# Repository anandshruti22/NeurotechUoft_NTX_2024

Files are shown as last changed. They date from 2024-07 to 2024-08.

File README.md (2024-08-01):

# NeurotechUoft_NTX_2024
The University of Toronto's Neurotechnology design team's submission to NTX competition 2024

## Contributors:
##### Software Subsystem: 
* Subsystem Lead: Shruti Anand (Undergrad Biomedical Engineering, Year 3) 
* Subsystem Members: Brandon Wong (Undergrad Computer Science, Year 2), Naoroj Farhan (Undergrad Computer Science, Year 1), Yunran Yang (Undergrad Computer Engineering, Year 2)
##### Hardware Subsystem:
* Subsystem Lead: Shuntaro Wakamatsu (Undergrad Computer Engineering, Year 3)
* Subsystem Members:
  Nafew Islam (Undergrad Mechanical Engineering, Year 2),
  Robert Youssef (Undergrad Mechanical Engineering, Year 2),
  Luna Sun (Undergrad Electrical Engineering, Year 2)

## Description of Project: 

About 15% of the world's population lives with some form of disability, of whom 2-4% experience significant difficulties in functioning. Among this statistic are individuals with weakened grip strength or hand amputees. Weakened grip strength or inability to perform grasping motions strongly limit the ability to perform daily household tasks. 

Our aim is to create a prototype of a mind controlled prosthetic hand that can conduct hand grasping motions based on the user’s thoughts. The objectives of our design are to: 
1) Create a prosthetic hand that can conduct the following two motions:
* Opening hand 
* Closing hand 

2) Identify the above two hand motions from EEG signals 

3) Retrieve relevant EEG signals from OpenBCI headset

## Pipeline:

The flow of data in our EEG controlled prosthetic hand works as follows:
1) Setup and Connection: Connect the OpenBCI headset to the OpenBCI Cyton board.
2) Data Transmission: Communicate with  Raspberry Pi through OpenBCI dongle. 
3) Data Streaming: Implement BrainFlow to stream EEG data live.
4) Data Processing : Run signal processing algorithms to denoise the EEG signals.
5) Machine Learning Model Execution : Execute the machine learning model to classify EEG signals.
6) Communication with Arduino: Send the result of the ML model to an Arduino via serial communication
7) Hand Motion: Arduino instructs the motors on the prosthetic hand to conduct the specified hand motion

## Navigation

Navigate through our repository and find the following information: 

* Software Subsystem: Our code to preprocess training data, train our ML model, and test our ML model using data we collected.
* Hardware Subsystem: Our CAD Files containing our prosthetic hand design, hand assembly instructions, Arduino code to control the hand, and a PCB design to be implemented in future iterations.
* Presentation: Our Presentation recording and the associated slides.

## Equipment and Software Installation: 

### Hardware Equipment required: 
* Raspberry Pi 4
* Arduino
* Jumper wires
* 2 Arduino Power Supply Modules
*  5 SG90 servo motors
*  PLA for 3d Printing
*  Rubber bands
*  USB-A to MicroUSB cable
*  2 AC to DC power coverters
  
### Software libraries to be installed: 
Read requirements.txt file for python libraries needed to run the code in the software subsystem folder.

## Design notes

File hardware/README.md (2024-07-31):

# EEG-Controlled Prosthetic Arm

## Overview
The EEG-Controlled Prosthetic Arm project aims to create a functional prosthetic arm that responds to brain signals. By integrating an EEG (electroencephalogram) headset, a 3D printed hand, a microcontroller, and servo motors, this project enables users to control the arm using their brain activity.

## CAD Files
The project includes the following CAD files:

- **Fingers**: There are 10 files for the fingers, each corresponding to a specific joint of a finger. These files are exported in both `.3mf` and `.f3d` formats (located in `hardware/CADfiles/3mf` and `hardware/CADfiles/f3d`, respectively).
- **Palm**: The palm design consists of two files: one cover and one main body (located in `hardware/CADfiles/palm`).
- **Shaft**: The shaft file (located in `hardware/CADfiles/shaft`) connects the finger joints. It has a diameter of approximately 2.8mm The shafts should be glued to the outer wall of the junction part so that it allows the inner part to move freely. The junction parts are designed not to bend more than 90 degrees or bend backwards.

## 3D Prints Assembly
To assemble the 3D prints:
- Place the motors inside the palm and glue them for maximum steadiness
- Put the string through the holes of each finger component
- Connect each finger joint using the 3D printed shafts.
- hook the rubber bands
- Push the cover of the palm into the main body (no need for gluing).

## Motors
The prosthetic arm features 5 SG90 servo motors placed inside the palm. Continuous motors were chosen because of their ability to keep winding. The choice of continuous motors allows for more rotations with a smaller radius, eliminating the need for bulky servo motor horns or attachments. This design optimization enables us to fit the motors comfortably inside the hand. Here's how they are set up:

- **Motor Placement**: The servo motors are strategically positioned within the palm to drive finger movements. There are small poles inside the palm that guides the string to its corresponding motor.
- **Control**: An Arduino microcontroller (tested with Arduino Due) runs the `control.ino` code (located in `hardware/ArduinoCode/control.ino`) to manage motor rotation.
- **String Mechanism**: For each finger, a strong (able to withstand at least 6kg of load) string (with a diameter of no more than 2.0 mm) is threaded through holes in the finger components. At the fingertip, the strings are securely tied to prevent them from slipping out. The other end of the strings is firmly attached to the servo motor shaft using modified servo motor horns and super glue. The horns create a groove where the strings wind and unwind.
- **Motor Control Wires**: (the group of wires in the red circle in the image below) The wires from the motors exit through five square windows at the wrist cross-section. The power pins (orange) receive 5V voltage and draw a current of 360mA. Since Arduino Due has only one 5V pin, two Arduino Power Supply Modules provide additional 4 5V power pins (2 power pins for each supply module). The ground pins (black) of the motors are connected to the same voltage. Control pins (yellow) are connected to the digital pins of the Arduino Due as follows:
  - Thumb:   Pin 2
  - Index:   Pin 9
  - Middle:  Pin 10
  - Ring:    Pin 11
  - Pinky:   Pin 12
  - 
- **Feedback Wires**: (the group of wires in the blue circle in the image above) On top of each finger, wires form a closed circuit. One end connects to a 3.3V power source, while the other end attaches to the analog pins of the Arduino Due:
  - Index:   A0
  - Middle:  A1
  - Ring:    A2
  - Pinky:   A3
  - A short jumper wire with woven edges ensures good contact. When the fingers are fully extended, the woven edges touch, creating a 3.3V signal. Arduino detects this and stops motor rotation.
  - On both sides of each finger, wires are attached to form a closed circuit. Electrons flow toward the fingertip on one side and return from the tip on the other side. (see the image below)
  - At the fingertip, a 1k ohm resistor is attached. This prevents the formation of a short circuit and ensures stable operation.
  - This closed circuit is independently implemented for each finger allowing the Arduino to control them separately.
  - 

- **Rubber Bands**: Plastic hair ties hooked onto small protrusions on each finger joint assist in retracting the fingers when the motor unwinds. Adjust their length to maintain tension.

## Arduino
Upload the "control.ino" file to the Arduino Due using the Arduino IDE software. Connect Arduino to the Raspberry Pi using a USB-A to MicroUSB cable for communication.

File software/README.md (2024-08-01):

# Files

## Raspberry Pi
```
├── real_time_processing.py: code loaded onto raspberry pi that interpets EEG signals and sends ML model output to Arduino via serial communication
```

## Data 

```
├── data_1_4_Hz
│   ├── processed training data files (bandpass filter of 1-4Hz + epoch)
├── data_13_17_Hz
│   ├── processed training data files (bandpass filter of 13-17Hz + baseline correction + epoch)
├── test_data
│   ├── processed test data files (bandpass filter of 1-4Hz + epoch)
│   ├── processed training data files (bandpass filter of 13-17Hz + baseline correction + epoch)
│   ├── data_collection_method.md: description on how test data was collected
│   ├── testing_model.md: python notebook where test data was used to see performance of model
```

## Preprocessing Code
```
├── Preprocessing
│   ├── preprocessing.ipynb: preprocessing code showing time frequency analysis and epoching
│   ├── citations.md: Details regarding citations justifying our use of C2, C4, Cz channels
│   ├── raw_data.md: Link to the raw data that is used for model training
```

## ML Model
```
├── ML Model
│   ├── model_training.ipynb: model training code
│   ├── model_with_delta.keras: model to be loaded
│   ├── model_description.md: Details regarding model architecture and citations
```

# How to run
To integrate with the prosthetic hand simple load the real_time_processing.py file along with the model_with_delta.keras file onto the Raspberry Pi. Then, run the real_time_preocessing.py code on the Raspberry Pi.

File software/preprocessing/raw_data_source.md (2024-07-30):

# Link to raw data used for preprocessing and training data
EEG Motor Movement/Imagery Dataset: https://www.physionet.org/content/eegmmidb/1.0.0/

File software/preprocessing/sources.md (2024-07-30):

# Citations

Yahya, Norashikin, et al. “Classification of Motor Functions from Electroencephalogram (EEG) Signals Based on an Integrated Method Comprised of Common Spatial Pattern and Wavelet Transform Framework.” Sensors (Basel, Switzerland), U.S. National Library of Medicine, 8 Nov. 2019, www.ncbi.nlm.nih.gov/pmc/articles/PMC6891287/.

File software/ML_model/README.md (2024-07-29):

# EEG Classification with Temporal Convolutional Neural Networks (TCNN)

## Overview
For our project, we used a temporal Convolution Neural Network that uses 1d convolutions over the EEG data and then makes a class prediction with a final sigmoid layer.
We did this for a few reasons:
- we faced significant issues with vanishing and exploding gradients when attempting to train an RNN/LSTM-based model for EEG classification tasks.
- RNNs/LSTMs take significantly longer to train well than CNNs

To address these challenges, we explored the use of Temporal Convolutional Neural Networks (TCNNs), which have shown success in similar tasks such as motion imagery classification (Lun et al., 2020). This document outlines the architecture, training strategy, and performance of our TCNN model.

## Model Architecture
We designed our TCNN model with the following key components and considerations:

- **Significant Dropout (80%)**: Applied to reduce overfitting to the training dataset.
- **He Initialization**: Used in convolutional layers to mitigate vanishing/exploding gradients (He et al., 2015).
- **Large Number of Filters**: Employed in the 1D convolutional layers (32, 64) to capture a richer set of features from the EEG input data.

Our model is inspired by the architecture used by Lun et al. but we simplified the architecture slightly to reduce overfitting in our specific task. Below is the model architecture the aforementioned paper used.
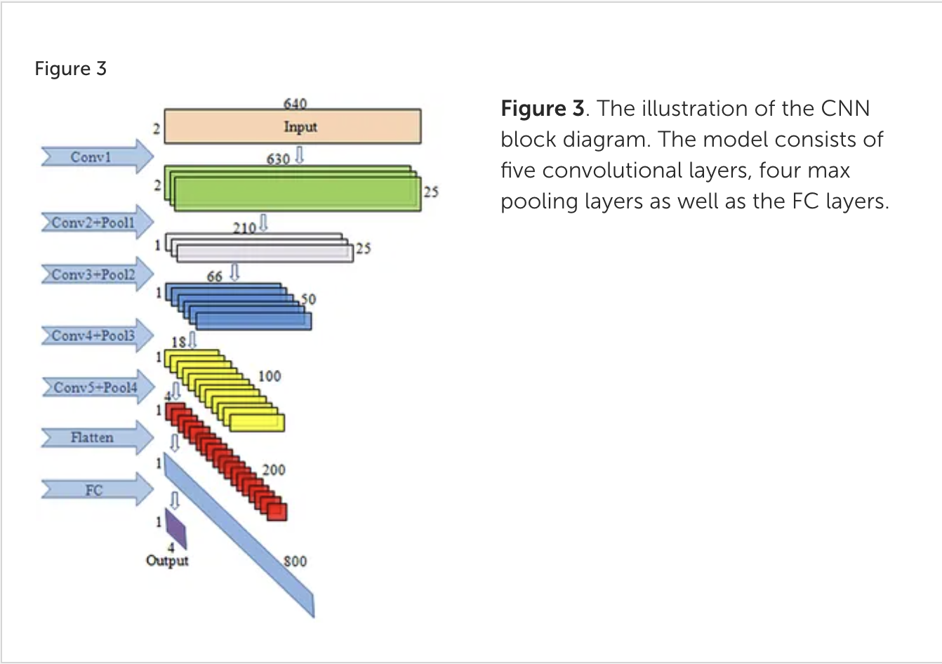
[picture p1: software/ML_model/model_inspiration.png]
Model Architecture

### Model Code
```python
from tensorflow.keras import layers, models, initializers

def create_model():
    dropout_rate = 0.2
    input_layer = layers.Input(shape=(401, 6))

    x = layers.Conv1D(filters=32, kernel_size=3, strides=2, activation='relu', kernel_initializer=initializers.HeNormal(), padding="same")(input_layer)
    x = layers.BatchNormalization()(x)
    x = layers.MaxPooling1D(pool_size=2, strides=2)(x)

    x = layers.Conv1D(filters=64, kernel_size=3, strides=2, activation='relu', kernel_initializer=initializers.HeNormal(), padding="same")(x)
    x = layers.BatchNormalization()(x)
    x = layers.MaxPooling1D(pool_size=2, strides=2)(x)

    x = layers.Conv1D(filters=128, kernel_size=3, strides=2, activation='relu', kernel_initializer=initializers.HeNormal(), padding="same")(x)
    x = layers.BatchNormalization()(x)
    x = layers.MaxPooling1D(pool_size=2, strides=2)(x)

    x = layers.Flatten()(x)

    x = layers.Dense(1024, activation="relu", kernel_initializer=initializers.HeNormal())(x)
    x = layers.Dropout(dropout_rate)(x)

    x = layers.Dense(256, activation="relu", kernel_initializer=initializers.HeNormal())(x)
    x = layers.Dropout(dropout_rate)(x)

    output_layer = layers.Dense(1, kernel_initializer=initializers.HeNormal(), activation="sigmoid")(x)

    return models.Model(inputs=input_layer, outputs=output_layer)
```

## Training Strategy
We employed several strategies to improve the performance and stability of our model:

- **Hyperparameter Tuning**: Adjusted learning rates, learning rate schedules, and the number of epochs.
- **Learning Rate Schedule**: Implemented to ensure stable convergence. If the model's loss did not improve after 3 epochs, the learning rate was reduced by 10%.
- **Repeated Training**: Conducted short training sessions (50 epochs) with hyperparameter adjustments to iteratively improve model performance.

### Key Considerations
1. **Dropout**: To counteract overfitting, significant dropout was applied. Initial experiments showed that training accuracy was often 15-20% higher than validation accuracy.
2. **Model Complexity**: While reducing the number of units in dense layers decreased both training and validation accuracy, maintaining a higher complexity was necessary to avoid high bias and variance.
3. **Vanishing/Exploding Gradients**: Although TCNNs are less prone to these issues compared to RNN/LSTM networks, He initialization was crucial to mitigate potential problems.

## Performance Metrics
Our evaluation metrics included binary accuracy, area under the curve (AUC), precision, and recall. We compared our model's performance against existing literature and other models trained on the same dataset.

### Results
- **Training Data**:
  - Classification Accuracy: 80%
  - Precision: 80%
  - Recall: 88%
  
- **Test Data**:
  - Classification Accuracy: 74%
  - Precision: 80%
  - Recall: 79%

These results are competitive with other machine learning models used for motor imagery tasks.

### Own Data Collection
We collected additional data in a manner similar to the dataset's original collection process. Our model achieved around 80% accuracy in predicting hand motions on this new data as well.

## Citation
He, K., Zhang, X., Ren, S., & Sun, J. (2015, February 6). Delving deep into rectifiers: Surpassing human-level performance on ImageNet Classification. arXiv.org. https://arxiv.org/abs/1502.01852 <br>
Lun, X., Yu, Z., Chen, T., Wang, F., & Hou, Y. (2020a, July 31). A simplified CNN classification method for Mi-EEG via the electrode pairs signals. Frontiers. https://www.frontiersin.org/articles/10.3389/fnhum.2020.00338/full#B10 

## Summary
Our approach focused on hyperparameter tuning and short epoch training sessions while adjusting learning rates and schedules to achieve stable convergence. The use of TCNNs with He initialization and significant dropout proved effective in addressing the vanishing/exploding gradient issues, resulting in competitive performance in EEG classification tasks.

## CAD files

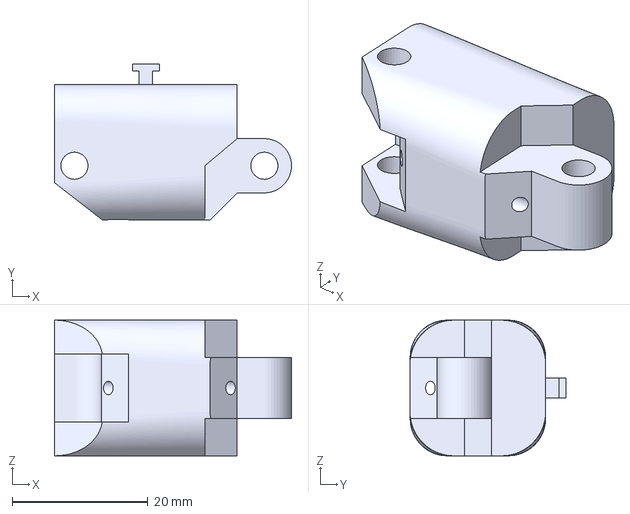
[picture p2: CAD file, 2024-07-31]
hardware/CADfiles/3mf/Middle Finger Second Joint Edited v7.3mf
34.9 x 23.0 x 20.0 mm

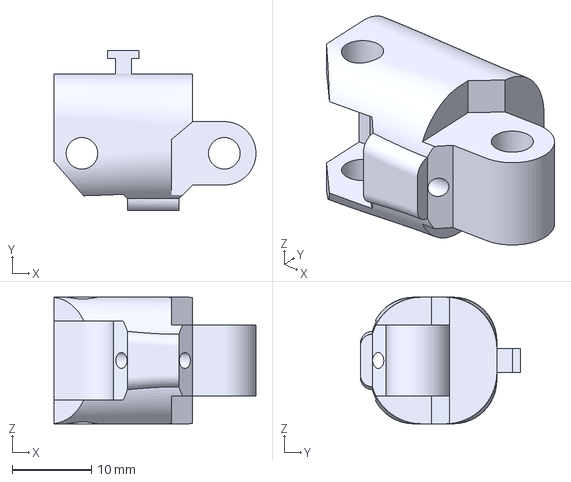
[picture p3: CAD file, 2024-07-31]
hardware/CADfiles/3mf/Pinky Finger Second Joint Edited v10.3mf
25.5 x 20.2 x 16.0 mm

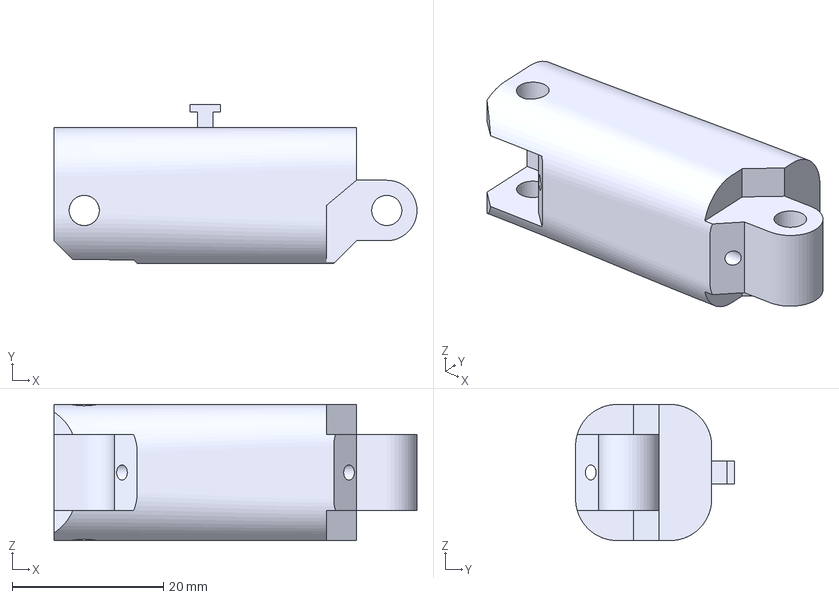
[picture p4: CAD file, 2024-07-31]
hardware/CADfiles/3mf/Ring Finger Base Joint v5.3mf
48.0 x 21.0 x 18.0 mm

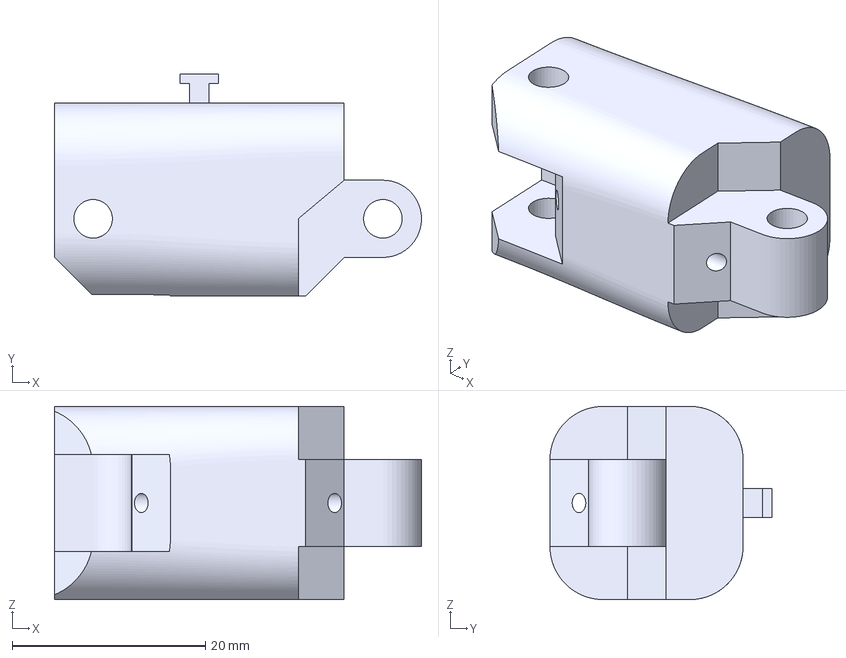
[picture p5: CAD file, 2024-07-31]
hardware/CADfiles/3mf/Thumb Base Joint v5.3mf
38.0 x 23.0 x 20.0 mm

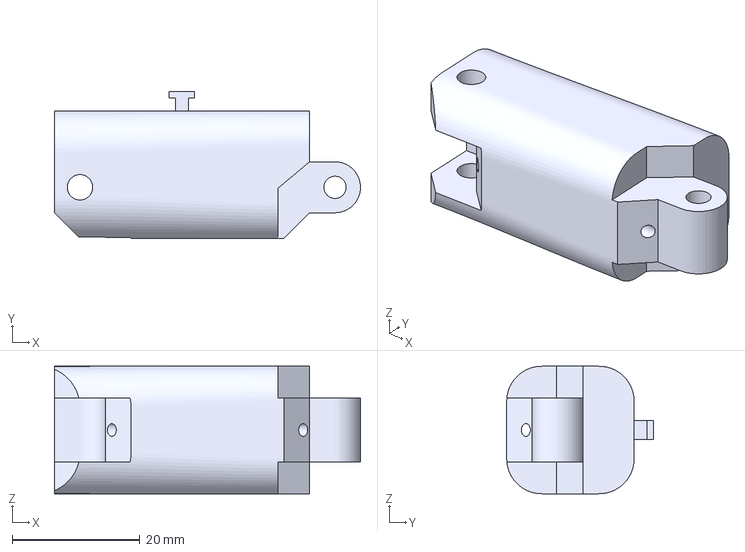
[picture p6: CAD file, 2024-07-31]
hardware/CADfiles/3mf/Index Finger Base Joint v5.3mf
48.0 x 23.0 x 20.0 mm

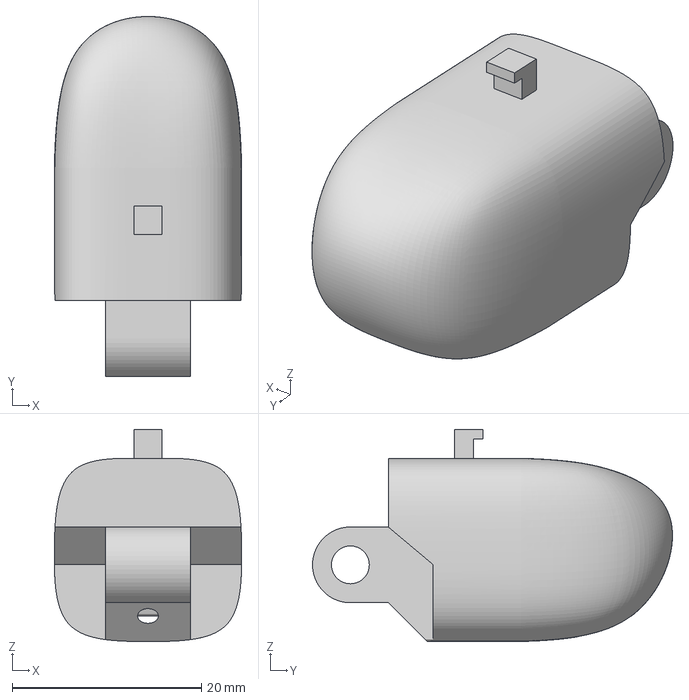
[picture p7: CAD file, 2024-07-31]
hardware/CADfiles/3mf/Tip Joint v6.3mf
19.8 x 38.0 x 22.4 mm

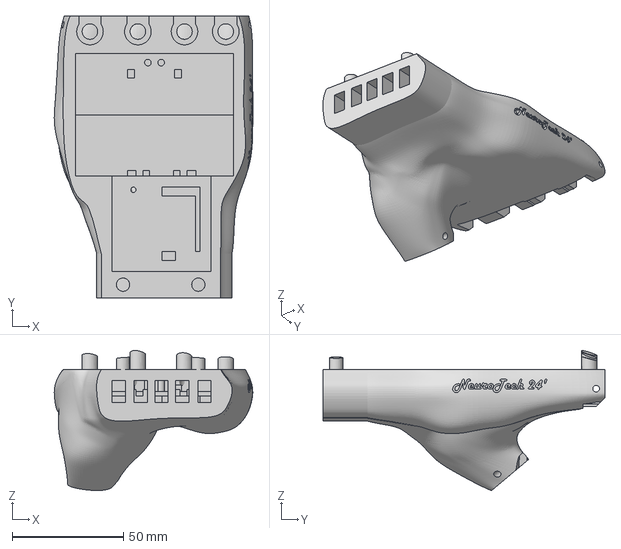
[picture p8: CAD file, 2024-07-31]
hardware/CADfiles/3mf/Palm7 v10.3mf
89.4 x 127.0 x 63.1 mm

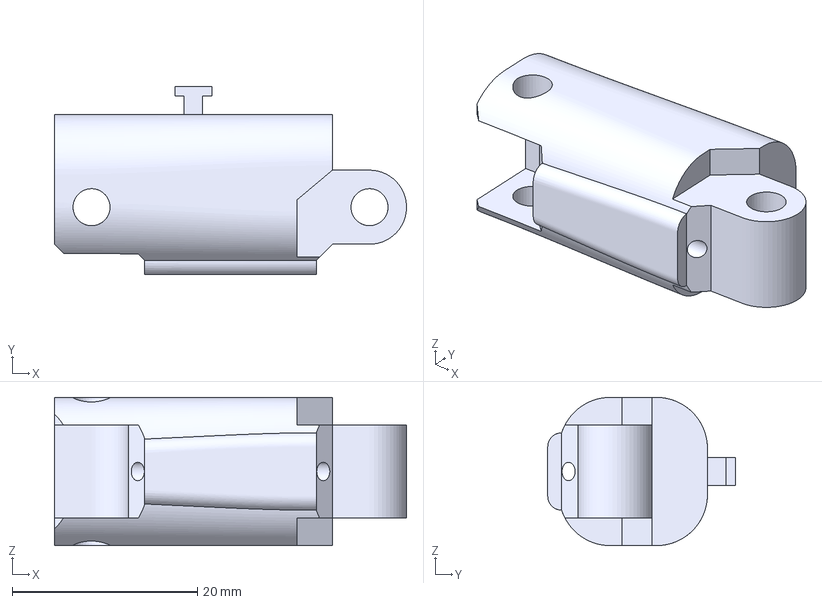
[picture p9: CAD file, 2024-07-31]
hardware/CADfiles/3mf/Pinky Finger Base Joint v6.3mf
38.0 x 20.2 x 16.0 mm

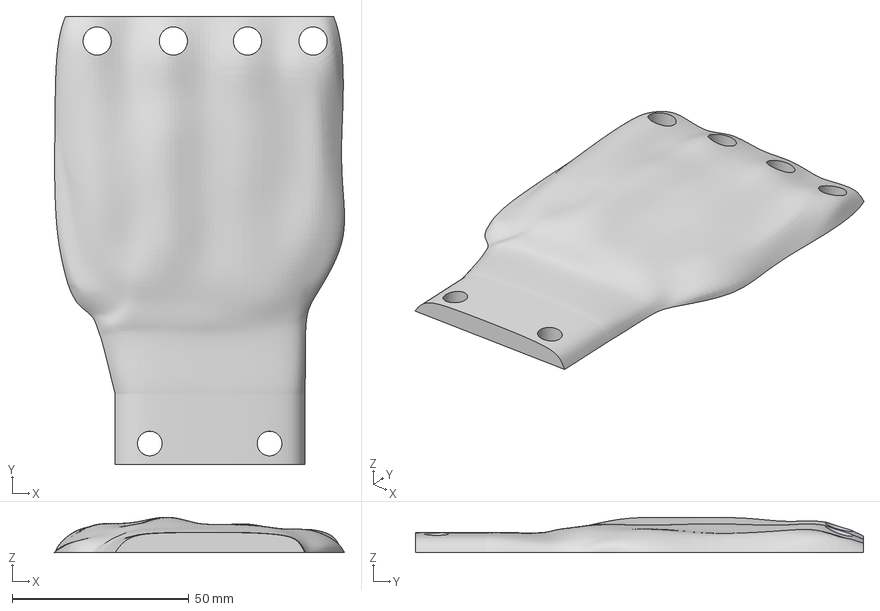
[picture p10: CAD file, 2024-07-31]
hardware/CADfiles/3mf/Palm6 v10.3mf
82.1 x 127.0 x 9.99 mm

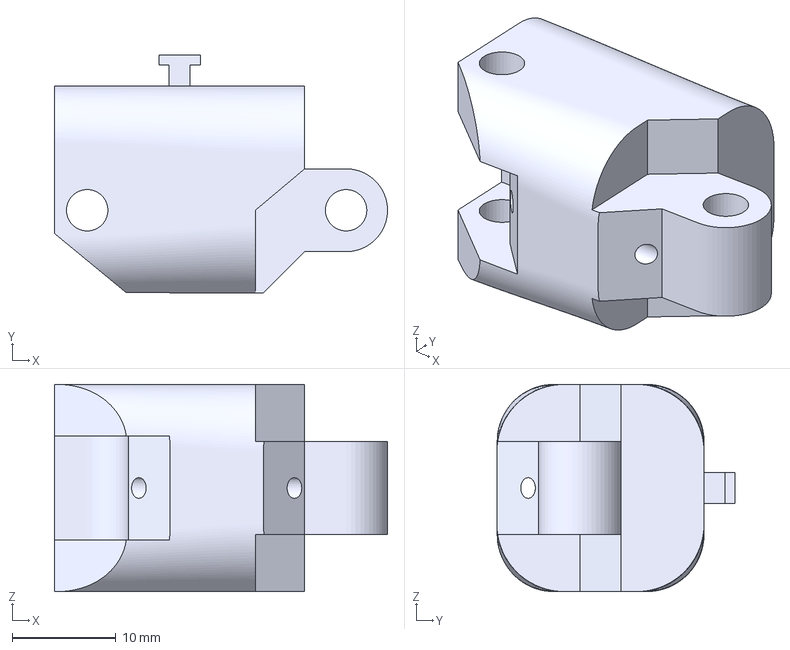
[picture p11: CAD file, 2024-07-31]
hardware/CADfiles/3mf/Index Finger Second Joint Edited v9.3mf
32.2 x 23.0 x 20.0 mm

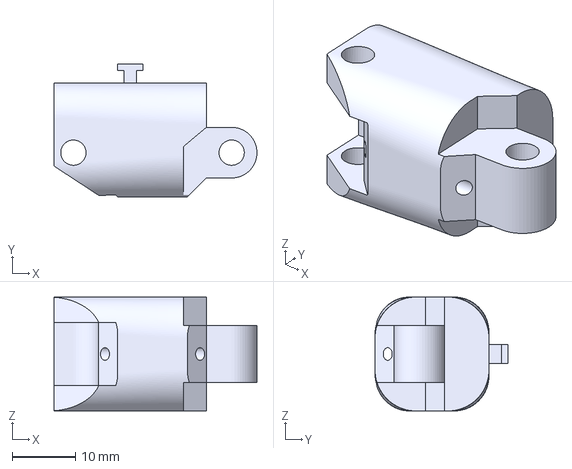
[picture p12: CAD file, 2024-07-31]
hardware/CADfiles/3mf/Ring Finger Second Joint Edited v9.3mf
32.1 x 21.0 x 18.0 mm

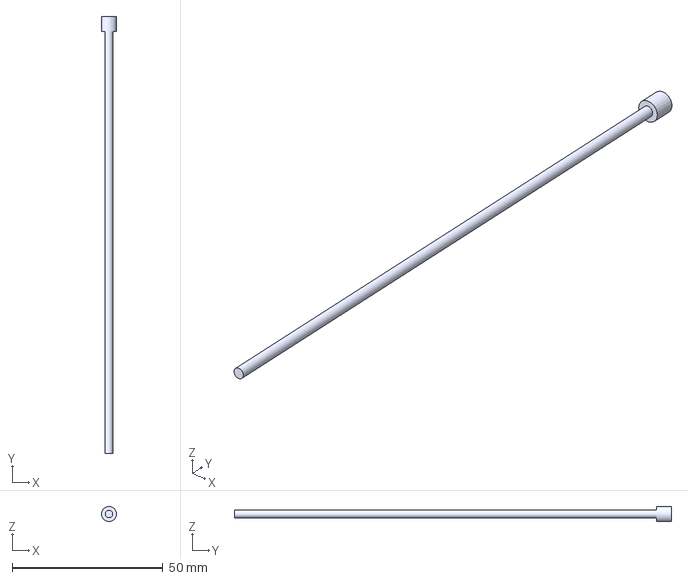
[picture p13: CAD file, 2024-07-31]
hardware/CADfiles/3mf/Hand_shaft v2.3mf
5.00 x 145.0 x 5.00 mm

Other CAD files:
hardware/CADfiles/f3d/Index Finger Base Joint v5.f3d
hardware/CADfiles/f3d/Index Finger Second Joint Edited v9.f3d
hardware/CADfiles/f3d/Middle Finger Second Joint Edited v7.f3d
hardware/CADfiles/f3d/Pinky Finger Base Joint v6.f3d
hardware/CADfiles/f3d/Pinky Finger Second Joint Edited v10.f3d
hardware/CADfiles/f3d/Ring Finger Base Joint v5.f3d
hardware/CADfiles/f3d/Ring Finger Second Joint Edited v9.f3d
hardware/CADfiles/f3d/Thumb Base Joint v5.f3d
hardware/CADfiles/f3d/Tip Joint v6.f3d
hardware/CADfiles/f3d/shaft.f3d

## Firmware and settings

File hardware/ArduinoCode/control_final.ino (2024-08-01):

#include <Servo.h>

//For 5 continuous servo motors:
Servo neuroServoIndex;
Servo neuroServoMiddle;
Servo neuroServoRing;
Servo neuroServoPinky;
Servo neuroServoThumb;


int pinsIndex   = 9;    //pin connection
int pinsMiddle  = 10;   //pin connection
int pinsRing    = 11;   //pin connection
int pinsPinky   = 12;   //pin connection
int pinsThumb   = 2;    //pin connection


int readIndex   = A0;
int readMiddle  = A1;
int readRing    = A2;
int readPinky   = A3;


void setup() {
 // put your setup code here, to run once:
 Serial.begin(9600);
 pinMode(LED_BUILTIN, OUTPUT);
 neuroServoIndex.attach(pinsIndex);
 neuroServoMiddle.attach(pinsMiddle);
 neuroServoRing.attach(pinsRing);
 neuroServoPinky.attach(pinsPinky);
 neuroServoThumb.attach(pinsThumb);

 pinMode(readIndex, INPUT);
 pinMode(readMiddle, INPUT);
 pinMode(readRing, INPUT);
 pinMode(readPinky, INPUT);

 if(closed(readIndex)){
  Serial.println("Index Ready");
 }
 else{
  Serial.println("Index NOT Ready");
 }
 if(closed(readMiddle)){
  Serial.println("Middle Ready");
 }
 else{
  Serial.println("Middle NOT Ready");
 }
 if(closed(readRing)){
  Serial.println("Ring Ready");
 }
 else{
  Serial.println("Ring NOT Ready");
 }
 if(closed(readPinky)){
  Serial.println("Pinky Ready");
 }
 else{
  Serial.println("Pinky NOT Ready");
 }
}

bool closed(int finger) {
  int r1 = analogRead(finger);
  int r2 = analogRead(finger);
  int r3 = analogRead(finger);

  if(r1 > 1000 && r2 > 1000 && r3 > 1000){
    Serial.println("yes");
    return true;
  }
  else{
    return false;
  }
}

void contract(int sig, Servo motor, int del, bool flag){
  int count = 0;
  while(!flag && count < 200){
    motor.write(0);
    delay(del);
    motor.write(90);
    flag    = closed(sig);
    bool temp_flag = closed(sig);
    flag = flag + temp_flag;
    count++;    
  }
}

void loop() {

 if (Serial.available()){
   char data = Serial.read();
   if (data == '1'){
     //Write to index, middle, ring, and pinky fingers
     digitalWrite(LED_BUILTIN, HIGH);
     neuroServoIndex.write(180);
     neuroServoMiddle.write(180);
     neuroServoRing.write(180);
     neuroServoPinky.write(180);
     delay(900);
     neuroServoIndex.write(90);
     neuroServoMiddle.write(90);
     delay(300);
     neuroServoPinky.write(90);
     delay(200);
     neuroServoRing.write(90);

     //Write to thumb
     neuroServoThumb.write(180);
     delay(400);
     neuroServoThumb.write(90);
   }
   else if (data == '0'){
    bool flagIndex    = closed(readIndex);  Serial.println((int)flagIndex);
    bool flagMiddle   = closed(readMiddle); Serial.println((int)flagMiddle);
    bool flagRing     = closed(readRing);   Serial.println((int)flagRing);
    bool flagPinky    = closed(readPinky);  Serial.println((int)flagPinky);

    contract(readPinky, neuroServoPinky, 4, flagPinky);
    contract(readRing, neuroServoRing, 6, flagRing);
    contract(readMiddle, neuroServoMiddle, 4, flagMiddle);
    contract(readIndex, neuroServoIndex, 6, flagIndex);
    // int counter = 0;

    // while((!(flagIndex && flagMiddle && flagRing && flagPinky)) && counter < 200){
    //   if(!flagIndex){
    //     neuroServoIndex.write(0);
    //     delay(8);
    //     neuroServoIndex.write(90);
    //     flagIndex    = closed(readIndex);
    //   }
    //   if(!flagMiddle){
    //     neuroServoMiddle.write(0);
    //     delay(4);
    //     neuroServoMiddle.write(90);
    //     flagMiddle    = closed(readMiddle);
    //           Serial.println(counter);
    //   }
    //   if(!flagRing){
    //     neuroServoRing.write(0);
    //     delay(4);
    //     neuroServoRing.write(90);
    //     flagRing    = closed(readRing);
    //   }
    //   if(!flagPinky){
    //     neuroServoPinky.write(0);
    //     delay(4);
    //     neuroServoPinky.write(90);
    //     flagPinky    = closed(readPinky);
    //   }
    //   counter++;
    //   // Serial.println(counter);
    // }

     //Write to thumb
     neuroServoThumb.write(0);
     delay(400);
     neuroServoThumb.write(90);
   }
 }
}

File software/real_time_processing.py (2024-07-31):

import mne
import numpy as np
import pandas as pd
import keras
import serial
import argparse
import time
import sys
import os
from tensorflow.python.keras.models import Model
from pprint import pprint

brainflow_path = os.path.expanduser('~/neurotech_project/brainflow/python_package')
if brainflow_path not in sys.path:
    sys.path.append(brainflow_path)

from brainflow.board_shim import BoardShim, BrainFlowInputParams, BoardIds, BrainFlowPresets
from tensorflow.keras.models import load_model


def parse_arguments():
    """ Parse command line arguments necessary for board configuration. """
    parser = argparse.ArgumentParser(description='Set up parameters for EEG board.')
    parser.add_argument('--timeout', type=int, help='timeout for device discovery or connection', required=False,
                        default=0)
    parser.add_argument('--ip-port', type=int, help='ip port', required=False, default=0)
    parser.add_argument('--ip-protocol', type=int, help='ip protocol, check IpProtocolType enum', required=False,
                        default=0)
    parser.add_argument('--ip-address', type=str, help='ip address', required=False, default='')
    parser.add_argument('--serial-port', type=str, help='serial port', required=False, default='')
    parser.add_argument('--mac-address', type=str, help='mac address', required=False, default='')
    parser.add_argument('--other-info', type=str, help='other info', required=False, default='')
    parser.add_argument('--serial-number', type=str, help='serial number', required=False, default='')
    parser.add_argument('--board-id', type=int, help='board id, check docs to get a list of supported boards',
                        required=True)
    parser.add_argument('--file', type=str, help='file', required=False, default='')
    parser.add_argument('--master-board', type=int, help='master board id for streaming and playback boards',
                        required=False, default=BoardIds.NO_BOARD)

    return parser.parse_args()


def setup_board(args):
    """ Setup and return a board with the given parameters. """
    params = BrainFlowInputParams()
    params.ip_port = args.ip_port
    params.serial_port = args.serial_port
    params.mac_address = args.mac_address
    params.other_info = args.other_info
    params.serial_number = args.serial_number
    params.ip_address = args.ip_address
    params.ip_protocol = args.ip_protocol
    params.timeout = args.timeout
    params.file = args.file
    params.master_board = args.master_board

    board = BoardShim(args.board_id, params)
    board.prepare_session()
    return board


def get_data(board, min_samples=401):
    while board.get_board_data_count() < min_samples:
        time.sleep(0.01)
    data = board.get_board_data()  # get all data and remove it from internal buffer
    return data


def process_realtime_data(data):
    """
    Processes realtime data
    """
    if data.shape[0] < 401:
        raise ValueError("Insufficient data samples available.")

    channel1 = data[3]
    channel2 = data[1]
    channel3 = data[2]
    final_array = np.array([channel1, channel2, channel3]).T
    print(final_array)

    original_freq = 250
    new_freq = 160
    reshaped_data = mne.filter.resample(final_array, axis=0, down=original_freq / new_freq)

    reshaped_data_1 = mne.filter.filter_data(reshaped_data, sfreq=160, l_freq=13, h_freq=17, verbose=False)
    reshaped_data_2 = mne.filter.filter_data(reshaped_data, sfreq=160, l_freq=1, h_freq=4, verbose=False)
    times = np.arange(len(reshaped_data)) / 160
    reshaped_data_new = mne.baseline.rescale(reshaped_data_1, times, (None, None), mode="mean")
    final_data = np.append(reshaped_data_new, reshaped_data_2, axis=1)

    print(reshaped_data.shape)
    reshaped = final_data.reshape(final_data.shape[1], final_data.shape[0])
    print(reshaped.shape)
    return reshaped


def epoch_realtime_data(data):
    """
    Processes realtime data and divides it into epochs of a specified length.
    Each epoch is transposed to fit the model's expected input shape of (401, 3).
    """
    processed_data = process_realtime_data(data)
    final_data = []

    epoch_length = 401  # Number of samples per epoch for approximately 1 second
    step_size = 401  # Set to epoch_length for no overlap (change if overlap is desired)

    lower_time = 0
    upper_time = epoch_length

    while upper_time <= processed_data.shape[0]:
        epoch = processed_data[lower_time:upper_time]
        epoch = epoch.T
        final_data.append(epoch)
        lower_time += step_size
        upper_time += step_size

    final_data = np.array(final_data)
    return final_data


def main():
    BoardShim.enable_dev_board_logger()

    args = parse_arguments()
    board = setup_board(args)
    board.start_stream()

    ser = serial.Serial('/dev/ttyUSB0', 19200)
    model = load_model('model_with_delta.keras', compile=True)

    try:
        while True:
            data = get_data(board)
            if data.shape[1] >= 401:  # Ensure we have enough samples to form an epoch
                final_data = epoch_realtime_data(data)
                old = 0
                for i in model.predict(final_data):
                    for j in i:
                        if old == 0 and j == 1:
                            ser.write(b'1')
                            print("Clench")
                        elif old == 1 and j == 0:
                            ser.write(b'0')
                            print("Unclench")
                        old = j
            else:
                print("Insufficient data. Waiting for more samples.")
                time.sleep(0.1)  # Sleep briefly to avoid high CPU usage when no data is available
    except KeyboardInterrupt:
        print("Stopping by user request.")
    except Exception as e:
        print(f"An error occurred: {e}")
    finally:
        try:
            board.stop_stream()
        except Exception as e:
            print(f"Failed to stop stream: {e}")
        board.release_session()
        ser.close()


if __name__ == '__main__':
    main()
import mne
import numpy as np
import serial
import argparse
import time
import sys
import os
from tensorflow.keras.models import load_model
from brainflow.board_shim import BoardShim, BrainFlowInputParams, BoardIds, BrainFlowPresets

brainflow_path = os.path.expanduser('~/neurotech_project/brainflow/python_package')
if brainflow_path not in sys.path:
    sys.path.append(brainflow_path)
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

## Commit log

2024-06-24 Added the servo motor control code
2024-07-30 Added Altium files
    [815.SchLib, Board.PcbDoc, MODULE_815.PcbLib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]
2024-07-31 added f3d files
    [Index Finger Base Joint v5.f3d, Index Finger Second Joint Edited v9.f3d, Middle Finger Second Joint Edited v7.f3d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]
2024-07-31 Added 3mf files
    [Hand_shaft v2.3mf, Index Finger Base Joint v5.3mf, Index Finger Second Joint Edited v9.3mf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]
2024-08-01 added the final version of the Arduino code
